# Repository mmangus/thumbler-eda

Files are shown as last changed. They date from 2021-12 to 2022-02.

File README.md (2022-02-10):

# thumbler-eda
EDA files for split keyboard with clicky encoder and thumb pointer





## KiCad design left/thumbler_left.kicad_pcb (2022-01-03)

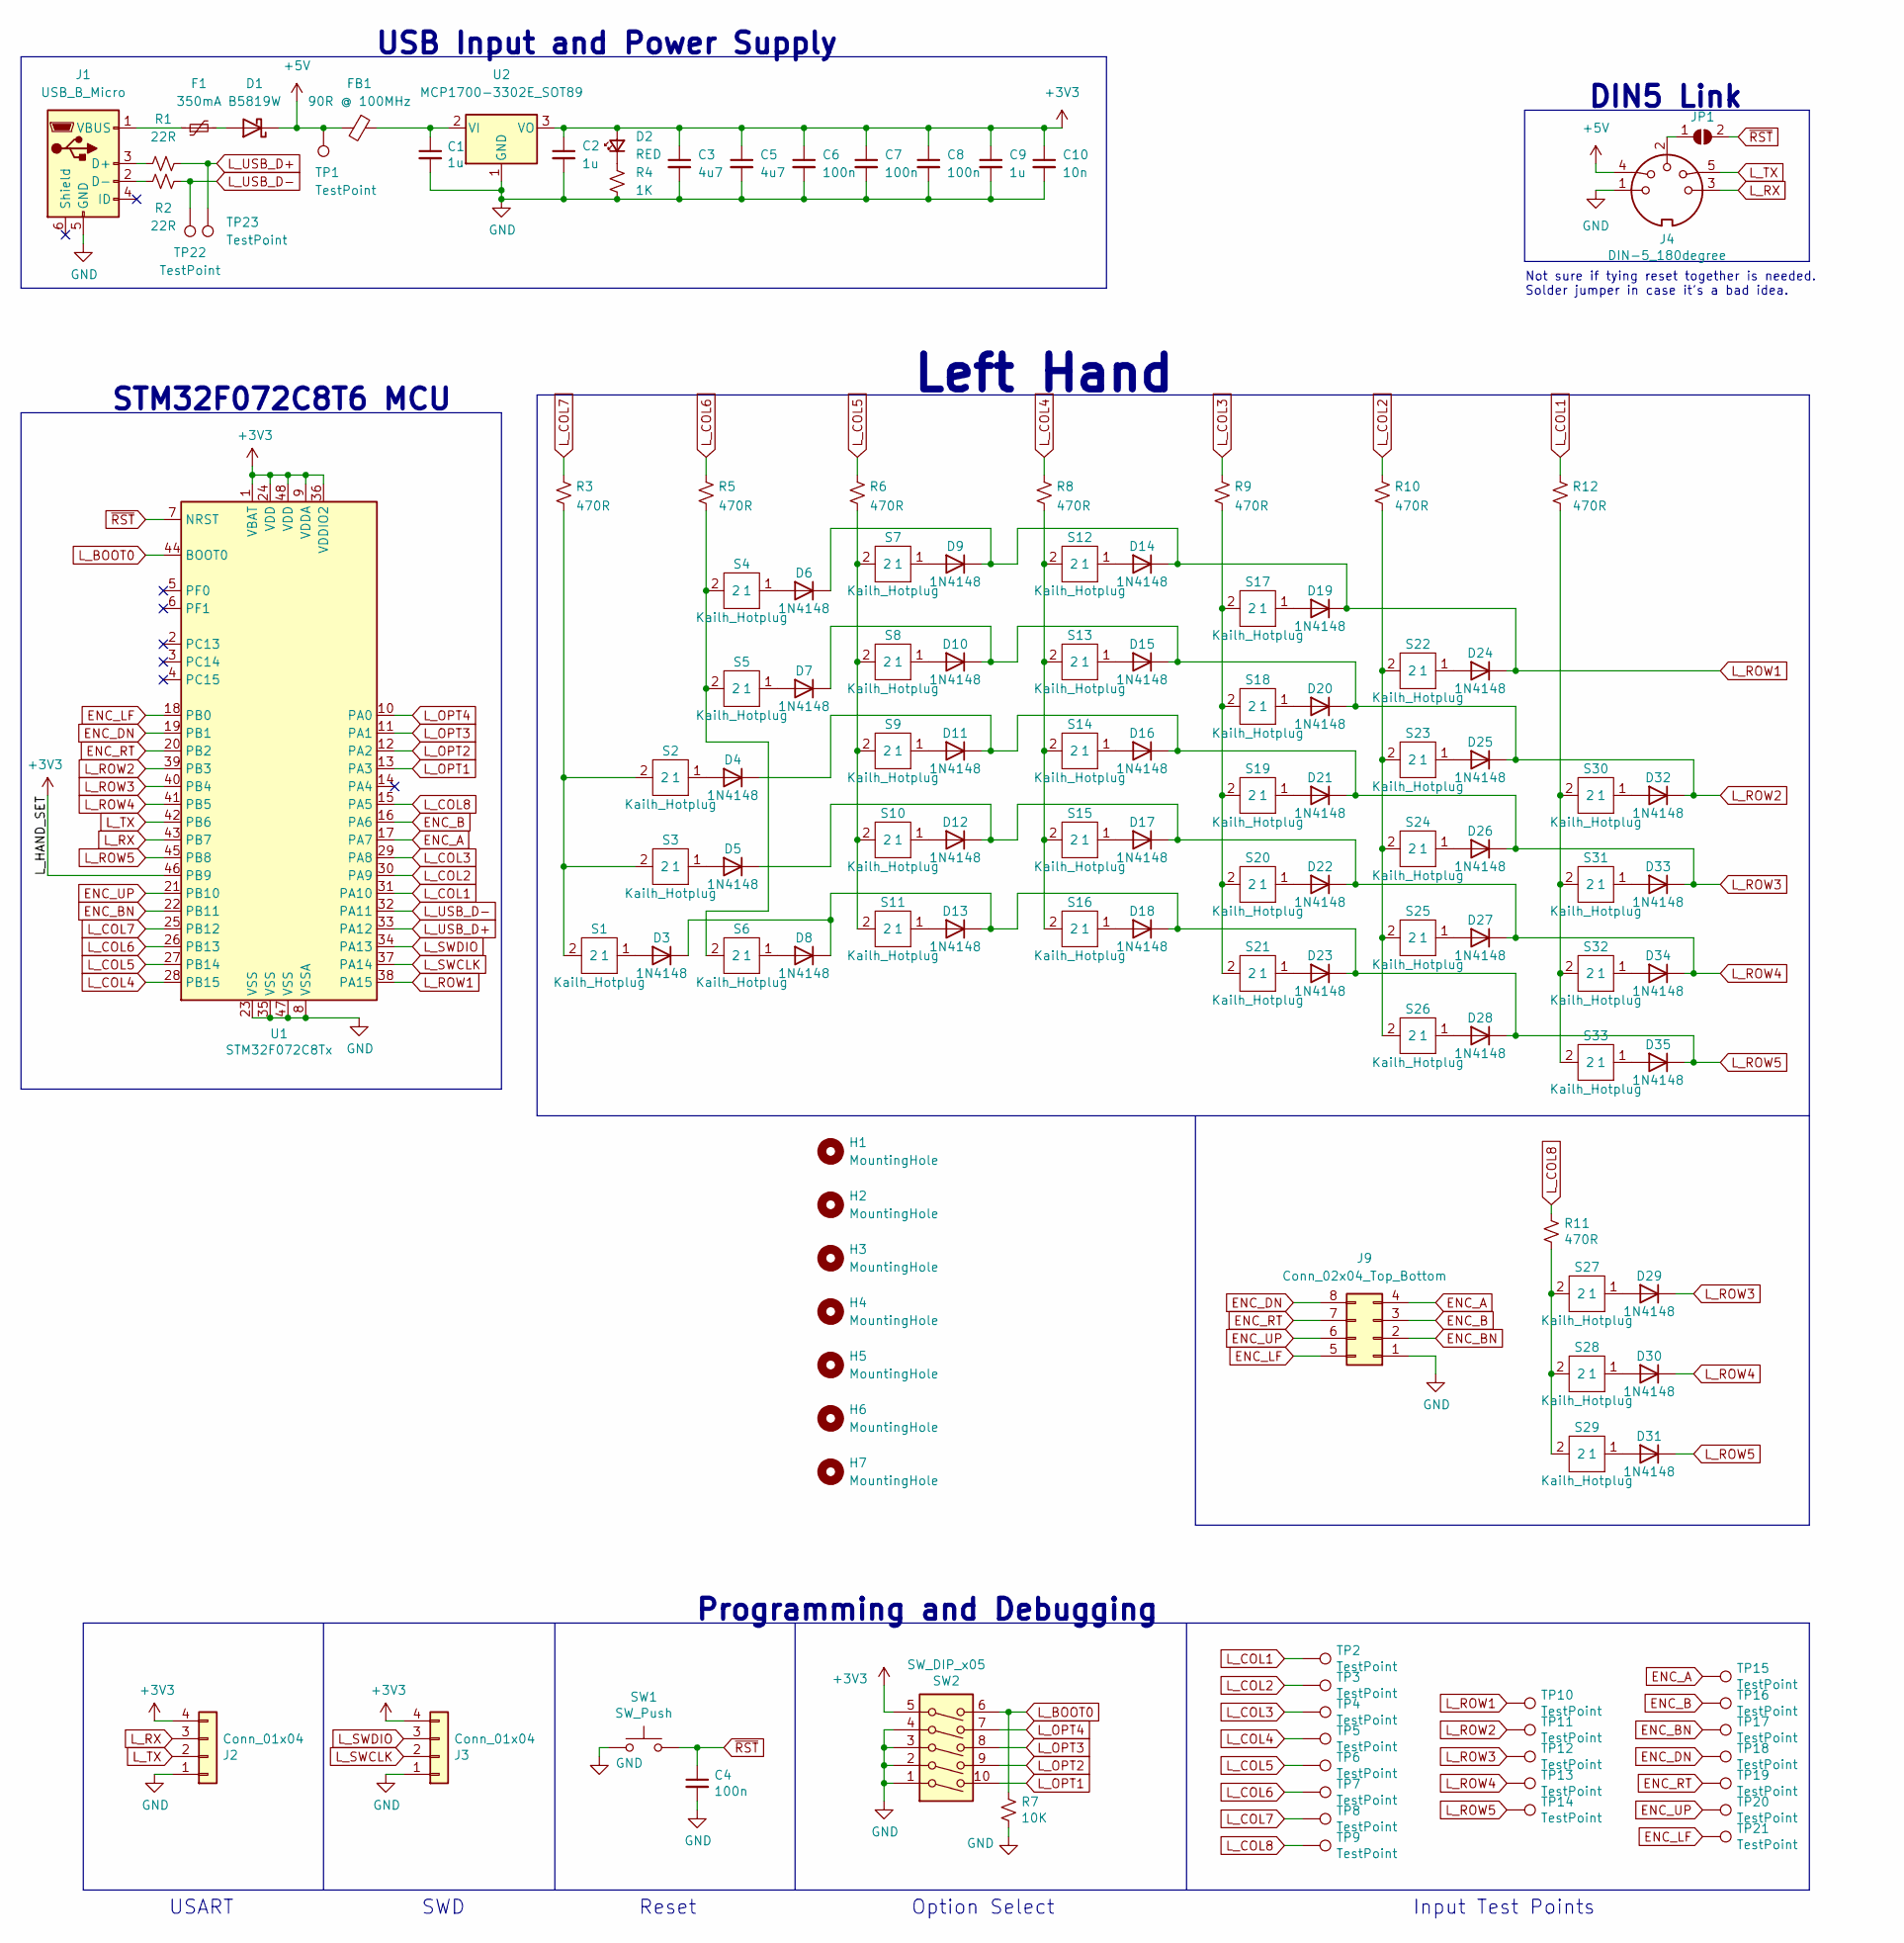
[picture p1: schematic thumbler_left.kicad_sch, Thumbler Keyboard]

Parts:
C1, C2: 1u; C_0805_2012Metric_Pad1.18x1.45mm_HandSolder
C3, C5: 4u7; C_0603_1608Metric_Pad1.08x0.95mm_HandSolder
C4: 100n; C_0805_2012Metric_Pad1.18x1.45mm_HandSolder
C6, C7, C8: 100n; C_0603_1608Metric_Pad1.08x0.95mm_HandSolder
C9: 1u; C_0603_1608Metric_Pad1.08x0.95mm_HandSolder
C10: 10n; C_0603_1608Metric_Pad1.08x0.95mm_HandSolder
D1: B5819W; D_SOD-123
D2: RED; LED_1206_3216Metric_Pad1.42x1.75mm_HandSolder
D3, D4, D5, D6, D7, D8, D9, D10, D11, D12, D13, D14, D15, D16, D17, D18, D19, D20, D21, D22, D23, D24, D25, D26, D27, D28, D29, D30, D31, D32, D33, D34, D35: 1N4148; D_DO-35_SOD27_P7.62mm_Horizontal
F1: 350mA; R_1812_4532Metric_Pad1.30x3.40mm_HandSolder
FB1: 90R @ 100MHz; L_0805_2012Metric_Pad1.15x1.40mm_HandSolder
H1, H2, H3, H4, H5, H6, H7: MountingHole; MountingHole_3.2mm_M3
J1: USB_B_Micro; USB_Micro-B_HRO_U-F-M5SS-W-1
J2, J3: Conn_01x04; PinHeader_2x02_P2.54mm_Vertical
J4: DIN-5_180degree; DIN5_180_CP-2350
J9: Conn_02x04_Top_Bottom; PinHeader_2x04_P2.54mm_Vertical
JP1: SolderJumper_2_Open; SolderJumper-2_P1.3mm_Open_TrianglePad1.0x1.5mm
R1, R2: 22R; R_0805_2012Metric_Pad1.20x1.40mm_HandSolder
R3, R5, R6, R8, R9, R10, R11, R12: 470R; R_0805_2012Metric_Pad1.20x1.40mm_HandSolder
R4: 1K; R_0805_2012Metric_Pad1.20x1.40mm_HandSolder
R7: 10K; R_0805_2012Metric_Pad1.20x1.40mm_HandSolder
S1, S2, S3, S4, S5, S6, S7, S8, S9, S10, S11, S12, S13, S14, S15, S16, S17, S18, S19, S20, S21, S22, S23, S24, S25, S26, S27, S28, S29, S30, S31, S32, S33: Kailh_Hotplug; Kailh_socket_MX_platemount
SW1: SW_Push; SW_PUSH-12mm
SW2: SW_DIP_x05; SW_DIP_SPSTx05_Slide_9.78x14.88mm_W7.62mm_P2.54mm
TP1, TP2, TP3, TP4, TP5, TP6, TP7, TP8, TP9, TP10, TP11, TP12, TP13, TP14, TP15, TP16, TP17, TP18, TP19, TP20, TP21, TP22, TP23: TestPoint; TestPoint_Pad_D2.0mm
U1: STM32F072C8Tx; LQFP-48_7x7mm_P0.5mm
U2: MCP1700-3302E_SOT89; SOT-89-3

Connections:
+3V3: C2.1, C3.1, C5.1, C6.1, C7.1, C8.1, C9.1, C10.1, D2.2 (A), J2.4, J3.4, SW2.5, U1.1 (VBAT), U1.9 (VDDA), U1.24 (VDD), U1.36 (VDDIO2), U1.46 (PB9), U1.48 (VDD), U2.3 (VO)
+5V: D1.1 (K), FB1.2, J4.4, TP1.1
ENC_A: J9.4, TP15.1, U1.17 (PA7)
ENC_B: J9.3, TP16.1, U1.16 (PA6)
ENC_BN: J9.2, TP17.1, U1.22 (PB11)
ENC_DN: J9.8, TP18.1, U1.19 (PB1)
ENC_LF: J9.5, TP21.1, U1.18 (PB0)
ENC_RT: J9.7, TP19.1, U1.20 (PB2)
ENC_UP: J9.6, TP20.1, U1.21 (PB10)
GND: C1.2, C2.2, C3.2, C4.2, C5.2, C6.2, C7.2, C8.2, C9.2, C10.2, J1.5 (GND), J2.1, J3.1, J4.1, J9.1, R4.2, R7.2, SW1.1, SW2.1, SW2.2, SW2.3, SW2.4, U1.8 (VSSA), U1.23 (VSS), U1.35 (VSS), U1.47 (VSS), U2.1 (GND)
L_BOOT0: R7.1, SW2.6, U1.44 (BOOT0)
L_COL1: R12.1, TP2.1, U1.31 (PA10)
L_COL2: R10.1, TP3.1, U1.30 (PA9)
L_COL3: R9.1, TP4.1, U1.29 (PA8)
L_COL4: R8.1, TP5.1, U1.28 (PB15)
L_COL5: R6.1, TP6.1, U1.27 (PB14)
L_COL6: R5.1, TP7.1, U1.26 (PB13)
L_COL7: R3.1, TP8.1, U1.25 (PB12)
L_COL8: R11.1, TP9.1, U1.15 (PA5)
L_OPT1: SW2.10, U1.13 (PA3)
L_OPT2: SW2.9, U1.12 (PA2)
L_OPT3: SW2.8, U1.11 (PA1)
L_OPT4: SW2.7, U1.10 (PA0)
L_ROW1: D6.1 (K), D9.1 (K), D14.1 (K), D19.1 (K), D24.1 (K), TP10.1, U1.38 (PA15)
L_ROW2: D7.1 (K), D10.1 (K), D15.1 (K), D20.1 (K), D25.1 (K), D32.1 (K), TP11.1, U1.39 (PB3)
L_ROW3: D4.1 (K), D11.1 (K), D16.1 (K), D21.1 (K), D26.1 (K), D29.1 (K), D33.1 (K), TP12.1, U1.40 (PB4)
L_ROW4: D5.1 (K), D12.1 (K), D17.1 (K), D22.1 (K), D27.1 (K), D30.1 (K), D34.1 (K), TP13.1, U1.41 (PB5)
L_ROW5: D3.1 (K), D8.1 (K), D13.1 (K), D18.1 (K), D23.1 (K), D28.1 (K), D31.1 (K), D35.1 (K), TP14.1, U1.45 (PB8)
L_RX: J2.3, J4.3, U1.43 (PB7)
L_SWCLK: J3.2, U1.37 (PA14)
L_SWDIO: J3.3, U1.34 (PA13)
L_TX: J2.2, J4.5, U1.42 (PB6)
L_USB_D+: R1.1, TP23.1, U1.33 (PA12)
L_USB_D-: R2.2, TP22.1, U1.32 (PA11)
unnamed: C1.1, FB1.1, U2.2 (VI)
unnamed: D1.2 (A), F1.2
unnamed: D2.1 (K), R4.1
unnamed: D3.2 (A), S1.1
unnamed: D4.2 (A), S2.1
unnamed: D5.2 (A), S3.1
unnamed: D6.2 (A), S4.1
unnamed: D7.2 (A), S5.1
unnamed: D8.2 (A), S6.1
unnamed: D9.2 (A), S7.1
unnamed: D10.2 (A), S8.1
unnamed: D11.2 (A), S9.1
unnamed: D12.2 (A), S10.1
unnamed: D13.2 (A), S11.1
unnamed: D14.2 (A), S12.1
unnamed: D15.2 (A), S13.1
unnamed: D16.2 (A), S14.1
unnamed: D17.2 (A), S15.1
unnamed: D18.2 (A), S16.1
unnamed: D19.2 (A), S17.1
unnamed: D20.2 (A), S18.1
unnamed: D21.2 (A), S19.1
unnamed: D22.2 (A), S20.1
unnamed: D23.2 (A), S21.1
unnamed: D24.2 (A), S22.1
unnamed: D25.2 (A), S23.1
unnamed: D26.2 (A), S24.1
unnamed: D27.2 (A), S25.1
unnamed: D28.2 (A), S26.1
unnamed: D29.2 (A), S27.1
unnamed: D30.2 (A), S28.1
unnamed: D31.2 (A), S29.1
unnamed: D32.2 (A), S30.1
unnamed: D33.2 (A), S31.1
unnamed: D34.2 (A), S32.1
unnamed: D35.2 (A), S33.1
unnamed: F1.1, J1.1 (VBUS)
unnamed: J1.2 (D-), R2.1
unnamed: J1.3 (D+), R1.2
unnamed: J4.2, JP1.1 (A)
unnamed: R3.2, S1.2, S2.2, S3.2
unnamed: R5.2, S4.2, S5.2, S6.2
unnamed: R6.2, S7.2, S8.2, S9.2, S10.2, S11.2
unnamed: R8.2, S12.2, S13.2, S14.2, S15.2, S16.2
unnamed: R9.2, S17.2, S18.2, S19.2, S20.2, S21.2
unnamed: R10.2, S22.2, S23.2, S24.2, S25.2, S26.2
unnamed: R11.2, S27.2, S28.2, S29.2
unnamed: R12.2, S30.2, S31.2, S32.2, S33.2
~RST: C4.1, JP1.2 (B), SW1.2, U1.7 (NRST)

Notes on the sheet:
Option Select
Reset
Programming and Debugging
USB Input and Power Supply
DIN5 Link
USART
STM32F072C8T6 MCU
SWD
Not sure if tying reset together is needed. Solder jumper in case it's a bad idea.
Input Test Points
Left Hand

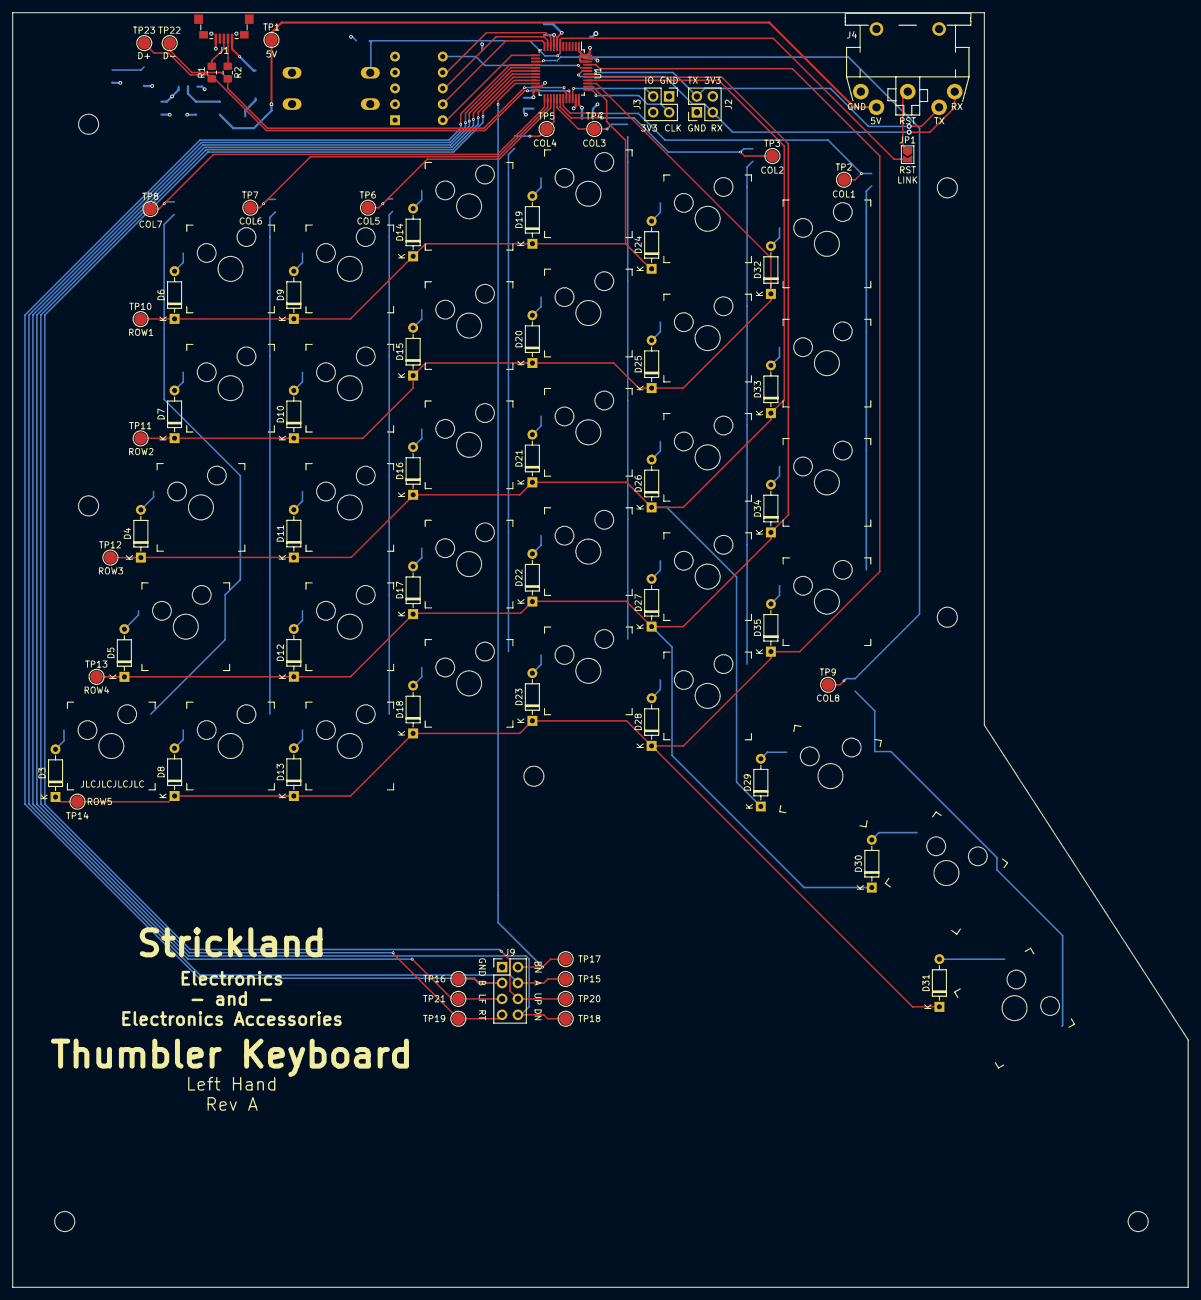
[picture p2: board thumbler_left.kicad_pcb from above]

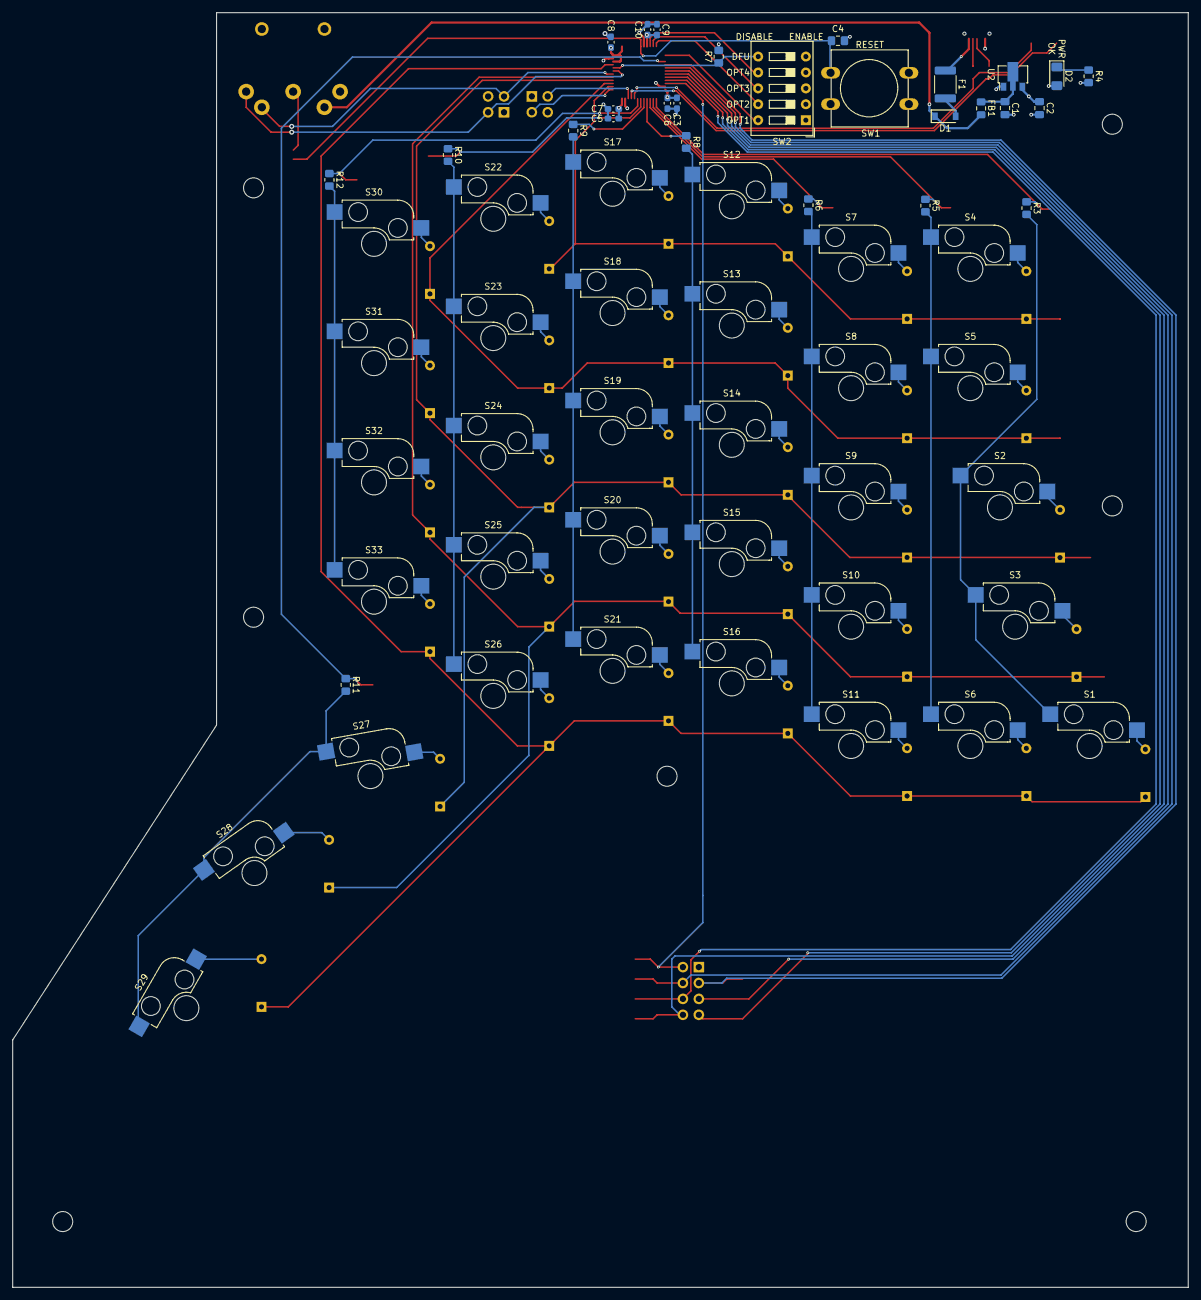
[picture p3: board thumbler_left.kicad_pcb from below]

Board: 4 copper layers, 187.8 x 203.6 mm, 132 parts (27 on the bottom side), 83 nets.

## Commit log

2021-11-27 add current limiting resistors to USB D+/-
    [thumbler.sch]
2021-11-29 thumb v0, options, optimizations
    [thumbler.sch]
2021-11-30 add footprint for ANO
    [thumbler.kicad_pcb, thumbler.sch]
2021-12-04 more protection, more footprints
    [thumbler.kicad_pcb, thumbler.sch]
2021-12-05 footprints done
    [thumbler.kicad_pcb, thumbler.sch]
2021-12-06 layout wip
    [thumbler.kicad_pcb, thumbler.sch]
2021-12-13 left side re-layout mostly done
    [thumbler.kicad_pcb, thumbler.sch]
2021-12-13 revised layout basically done, minus thumbs
    [thumbler.kicad_pcb]
2021-12-13 fix right enter placement; still need to reannotate
    [thumbler.kicad_pcb]
2021-12-13 minor tidying
    [thumbler.kicad_pcb]
2021-12-26 70 key laid out
    [thumbler.kicad_pcb, thumbler.sch]
2021-12-26 all TPs to front
    [thumbler.kicad_pcb]
2021-12-26 test points and current-limiting resistors placed
    [thumbler.kicad_pcb]
2021-12-31 left mostly routed; kicad 6; need to cleanup files...
    [enc_breakout.kicad_pcb, enc_breakout.kicad_sch, thumbler.kicad_pcb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]
2021-12-31 more routing
    [thumbler.kicad_pcb, thumbler.kicad_sch]
2022-01-01 staritng to split files
    [thumbler_left-B_Cu.gbr, thumbler_left-B_Mask.gbr, thumbler_left-B_Paste.gbr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]
2022-01-01 tweak mounting holes
    [thumbler_left-B_Cu.gbr, thumbler_left-B_Mask.gbr, thumbler_left-B_Paste.gbr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]
2022-01-03 restructuring and getting close
    [enc_breakout-B_Cu.gbr, enc_breakout-B_Mask.gbr, enc_breakout-B_Silkscreen.gbr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]
2022-01-03 ready to manufacture?
    [thumbler_left-B_Cu.gbr, thumbler_left-B_Mask.gbr, thumbler_left-B_Paste.gbr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]
2022-01-03 commit right side gerber
    [thumbler_right-B_Cu.gbr, thumbler_right-B_Mask.gbr, thumbler_right-B_Paste.gbr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]
2022-01-03 dont commit encoder breakout backups either
